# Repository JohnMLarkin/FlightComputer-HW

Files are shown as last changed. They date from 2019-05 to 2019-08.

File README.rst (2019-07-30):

***************************
HABOSC Flight Computer (HW)
***************************






Overview
========

The High Altitude Balloon Open Source Collection (HABOSC) is a set of interrelated tools for transmitting telemetry from a high altitude balloon, processing and storing that data, and providing user access to the stored data both during and after the flight. The system is designed to be flexible so it can adapt to the needs of various users.

One of the components of the HABOSC is the **Flight Computer**. The Flight Computer consists of a microcontroller and supporting hardware (battery, SD card, and XBee radio module) and comes in two configurations. The *standard* Flight Computer includes a clip to hold a half-size breadboard and the *mini* does not, reducing both its size and weight.

The Flight Computer is intended to be carried by individual experiment pods. The microcontroller can be flexibly programmed to interface with a wide variety of sensors. Data can be stored on the SD card or relayed to the ground using an XBee radio link to the Command Module. The microcontroller's software is written in C++ using the Arm\ :sup:`®` Mbed\ :sup:`™` OS.

This repository contains the *hardware* portion of the Flight Computer and supporting documentation.

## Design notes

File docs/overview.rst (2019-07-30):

High Altitude Balloon Open Source Collection
============================================

The High Altitude Balloon Open Source Collection (HABOSC) is a set of interrelated tools for transmitting telemetry from a high altitude balloon, processing and storing that data, and providing user access to the stored data both during and after the flight.  The system is designed to be flexible so it can adapt to the needs of various users.

The components of the collection are:

Command Module (hardware)
  This is the essential hardware system carried by the balloon.  The core tracking features are implemented using a GPS receiver and an Iridium satellite modem.
  The operations of the Command Module are coordinated by a microcontroller.  Bluetooth communication allows the Command Module to be configured for the flight shortly before launch (see the Launch Control tool below).
  Communication with experiment pods containing a Flight Computer (see below) is possible through a XBee 802.15.4 radio network operating at 2.4 GHz.

Command Module (microcontroller software)
  Written in C++ using the Arm\ :sup:`®` Mbed\ :sup:`™` OS, this is the code running on the microcontroller that ensures measurements are made and then transmitted to the Iridium satellite network.

Mission Control (server software)
  Running on a server, this Javascript code listens for telemetry packets relayed by the Iridium ground station via email.  The telemetry data is processed and stored in a MongoDB database.  Users interface with Mission Control through a web frontend.  Close to real-time mapping and graphical display of key telemetry is provided.

Launch Control (laptop or desktop application)
  Using the cross-platform Electron framework, this software allows a Bluetooth-enabled computer to communicate with the Command Module prior to launch.  It synchronizes the mission configuration between Command Module and Mission Control.  This application also allows users to monitor communication between the Command Module and linked Flight Computers during the prototyping and debugging phase on the ground.

Flight Computer (hardware)
  This printed circuit board holds an Arm Cortex-M3 microcontroller.  The microcontroller supports reading sensors and logging data to the attached SD card.  An XBee radio modem allows the microcontroller to synchronize its real-time clock with the Command Module as well as to relay data to the Command Module for transmission to Mission Control. An integrated rechargeable battery provides a reliable power source.  A version of the Flight Computer also provides a base for attaching a breadboard if custom circuitry is required.

Flight Computer (software library)
  This Mbed OS library allows users to easily integrate communication with the Command Module into their C++ code.

..  list-table:: Collection Links
    :header-rows: 1

    * - Component
      - Repository
      - Documentation
    * - Command Module (HW)
      - not yet available
      - not yet available
    * - Command Module (SW)
      - `GitHub <https://github.com/JohnMLarkin/Whitworth-CommandModule>`_
      - not yet available
    * - Mission Control
      - `GitHub <https://github.com/JohnMLarkin/Mission-Control>`_
      - not yet available
    * - Launch Control
      - `GitHub <https://github.com/JohnMLarkin/Whitworth-LaunchControl>`_
      - not yet available
    * - Flight Computer (HW)
      - `GitHub <https://github.com/JohnMLarkin/FlightComputer-HW>`_
      - not yet available
    * - Flight Computer (SW)
      - `GitHub <https://github.com/JohnMLarkin/FlightComputer-SW>`_
      - not yet available

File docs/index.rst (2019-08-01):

.. HABOSC Flight Computer (HW) documentation master file, created by
   sphinx-quickstart on Wed Jul 31 14:32:50 2019.
   You can adapt this file completely to your liking, but it should at least
   contain the root `toctree` directive.

.. include:: ../README.rst

.. toctree::
   :maxdepth: 3
   :numbered:
   :caption: Contents:

   overview
   fabrication
   parts
   assembly

Indices and tables
==================

* :ref:`genindex`
* :ref:`modindex`
* :ref:`search`

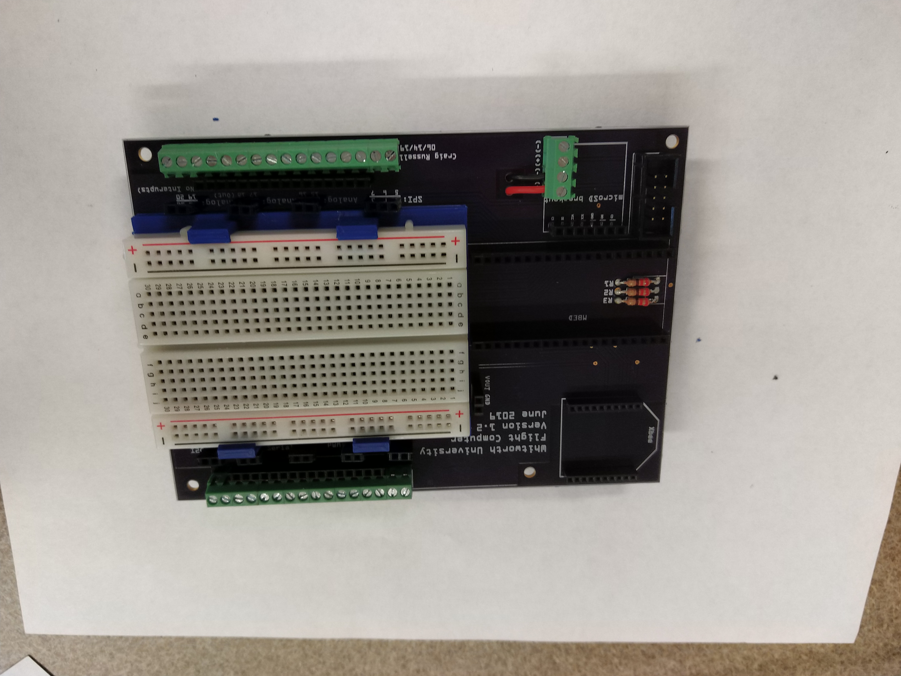
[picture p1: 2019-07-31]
docs/img/breadboard.jpg

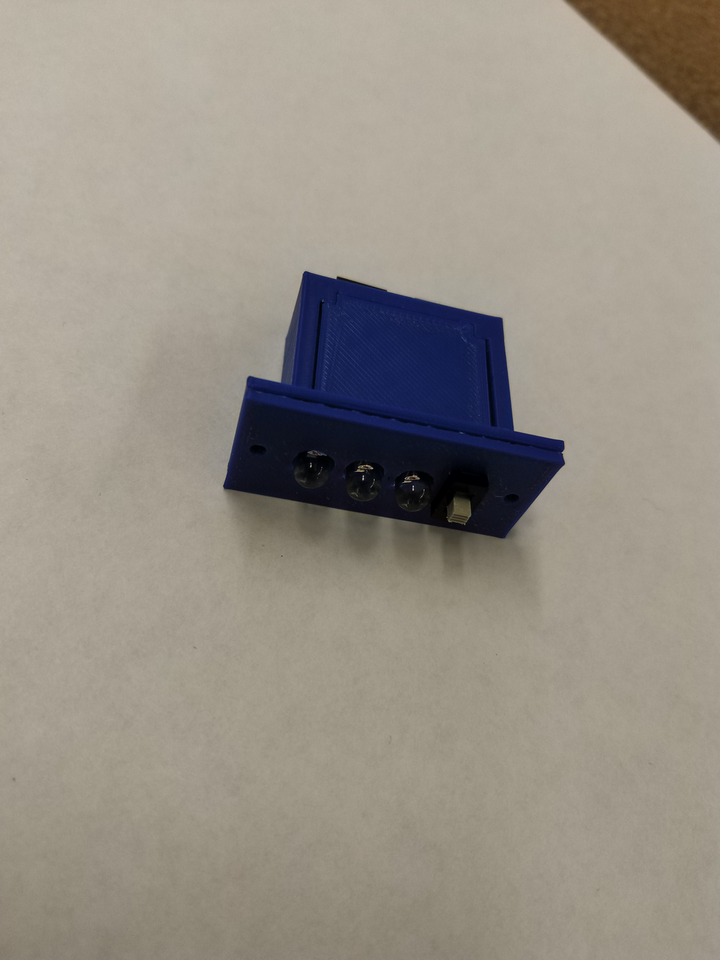
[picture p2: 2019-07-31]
docs/img/capOnBox.jpg

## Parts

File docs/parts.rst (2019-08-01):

Standard Parts
==============

Assembly of a Flight Computer requires the following electronic components and connection hardware.

..  list-table:: Common components for either Flight Computer
  :header-rows: 1
  :widths: auto

  * - Description
    - Manufacturer
    - Part Number
    - Quantity
    - Link
  * - 20 pin header socket (for mbed)
    - Sullins
    - PPPC201LFBN-RC
    - 2
    - `Digi-Key <https://www.digikey.com/product-detail/en/sullins-connector-solutions/PPPC201LFBN-RC/S7053-ND/810192>`__
  * - XBee socket (2 mm, 10 pin, set of 2)
    - Adafruit
    - 366
    - 1
    - `Digi-Key <https://www.digikey.com/product-detail/en/adafruit-industries-llc/366/1528-1392-ND/5629440>`__
  * - 2x5 IDC connector receptacle (female sockets)
    - Wurth Electronics
    - 61201023021
    - 2
    - `Digi-Key <https://www.digikey.com/product-detail/en/wurth-electronics-inc/61201023021/732-2102-ND/2060598>`__
  * - 2x5 IDC connector header (male pin)
    - Wurth Electronics
    - 61201021621
    - 2
    - `Digi-Key <https://www.digikey.com/product-detail/en/wurth-electronics-inc/61201021621/732-2094-ND/2060590>`__
  * - 2-pin screw terminal block, 3.5 mm pitch
    - Wurth Electronics
    - 691214110002
    - 18
    - `Digi-Key <https://www.digikey.com/product-detail/en/wurth-electronics-inc/691214110002/732-2747-ND/2508516>`__
  * - 220 |ohm|, 1/4 W resistor
    - 
    -
    - 3
    - `Digi-Key <https://www.digikey.com/product-detail/en/stackpole-electronics-inc/CF14JT220R/CF14JT220RCT-ND/1830334>`__
  * - LED, 5 mm, red
    - Cree
    - C503B-RCN-CW0Z0AA1
    - 1
    - `Digi-Key <https://www.digikey.com/product-detail/en/cree-inc/C503B-RCN-CW0Z0AA1/C503B-RCN-CW0Z0AA1-ND/1922930>`__
  * - LED, 5 mm, green
    - Cree
    - C503B-GCS-CY0C0791
    - 1
    - `Digi-Key <https://www.digikey.com/product-detail/en/cree-inc/C503B-GCS-CY0C0791/C503B-GCS-CY0C0791-ND/1922941>`__
  * - LED, 5 mm, blue
    - Cree
    - C503B-BCN-CV0Z0461
    - 1
    - `Digi-Key <https://www.digikey.com/product-detail/en/cree-inc/C503B-BCN-CV0Z0461/C503B-BCN-CV0Z0461-ND/1922945>`__
  * - Slide switch, SPDT
    - NKK Switches
    - AS13AP
    - 1
    - `Digi-Key <https://www.digikey.com/product-detail/en/nkk-switches/AS13AP/360-2124-ND/1014820>`__
  * - mbed LPC1768 microcontroller
    - NXP
    - OM11043
    - 1
    - `Digi-Key <https://www.digikey.com/product-detail/en/nxp-usa-inc/OM11043,598/568-4916-ND/2138502>`__
  * - XBee 3 radio module
    - Digi
    - XB3-24Z8PT
    - 1
    - `Digi-Key <https://www.digikey.com/product-detail/en/digi-international/XB3-24Z8PT/602-2191-ND/8130937>`__
  * - microSD breakout
    - SparkFun
    - BOB-00544
    - 1
    - `Digi-Key <https://www.digikey.com/product-detail/en/sparkfun-electronics/BOB-00544/1568-1345-ND/5824094>`__
  * - 7.4 V, 800 mAh LiPo battery with PCB
    - Tenergy
    - 31145
    - 1
    - `Tenergy <https://power.tenergy.com/search.php?search_query=31145>`__
  * - Male Tamiya connector, 20 AWG silicon wire
    - Tenergy
    - 80001-5
    - 1
    - `Tenergy <https://power.tenergy.com/standard-male-tamiya-connector-battery-side/>`__ 

A charger for the battery is also required. For the battery pack specified, an appropriate choice is the Tenergy TLP-2000 (`Tenergy <https://power.tenergy.com/tenergy-tlp-2000-smart-charger-for-li-ion-lipo-battery-packs-3-7v-14-8v/>`__). This charger can be shared among multiple Flight Computers.

Connecting the Flight Computer PCB to the external interface also requires flat ribbon cable (10 conductors).  We buy this by the meter (`Digi-Key <https://www.digikey.com/product-detail/en/wurth-electronics-inc/63911015521CAB/732-11801-ND/8324551>`__) and cut an appropriate length.

We also use standard perf board (like `this <https://www.digikey.com/product-detail/en/vector-electronics/64P44XXXP/V1043-ND/37918>`__) in the assembly of the external interface. You just need a 2 hole by 5 hole piece so this might easily be scrap from some other project.

Additions for Standard Flight Computer
--------------------------------------

If you are assembling a **standard** Flight Computer, you will also need female header sockets in various lengths (with 2.54 mm pitch).  Those lengths and the number required are:

* 16 pins (2)
* 7 pins (1)
* 3 pins (1)
* 2 pins (9)

We use breakaway female header strip and cut it to length. Cutting always sacrifices one pin and then the edges are smoothed. We have had good success with Adafruit's 598 (5 pack of 36-pin strips) and the price is less than many other options (`Digi-Key <https://www.digikey.com/products/en?keywords=1528-2537-ND>`__).

The breadboard clip on the standard Flight Computer (one of the custom 3D printed components) is designed for a half-size solderless breadboard (for example, Adafruit's `64 <https://www.digikey.com/product-detail/en/adafruit-industries-llc/64/1528-2182-ND/7241427>`__). If you want something more permanent than a solderless breadboard, Adafruit makes a `perma-proto half-sized breadboard PCB <https://www.digikey.com/products/en/prototyping-fabrication-products/prototype-boards-perforated/636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>`__ that has the same mounting hole spacing as our breadboard clip.

Addition for Mini Flight Computer
---------------------------------

If you are assembling a **mini** Flight Computer, you will also need a 3-pin screw terminal block (with 3.5 mm pitch). We use Wurth Electronics part 691214110003 (`Digi-Key <https://www.digikey.com/product-detail/en/wurth-electronics-inc/691214110003/732-2748-ND/2508517>`__).

.. |ohm| unicode:: U+03a9 ..  capital omega

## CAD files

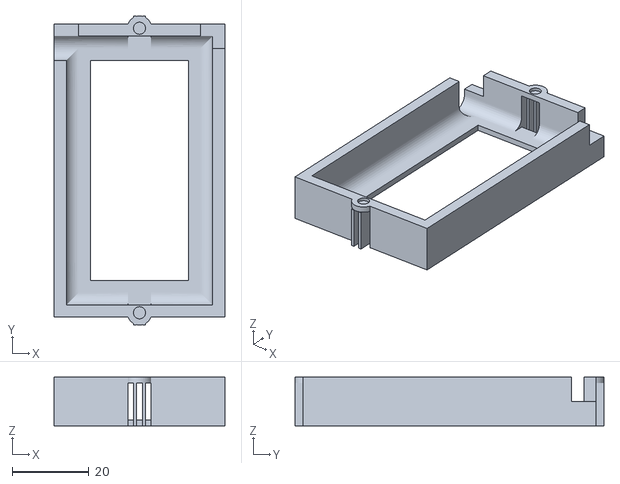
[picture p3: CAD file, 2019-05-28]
3d_print/battery_holder/battery clip.stl
44.5 x 80.4 x 12.7

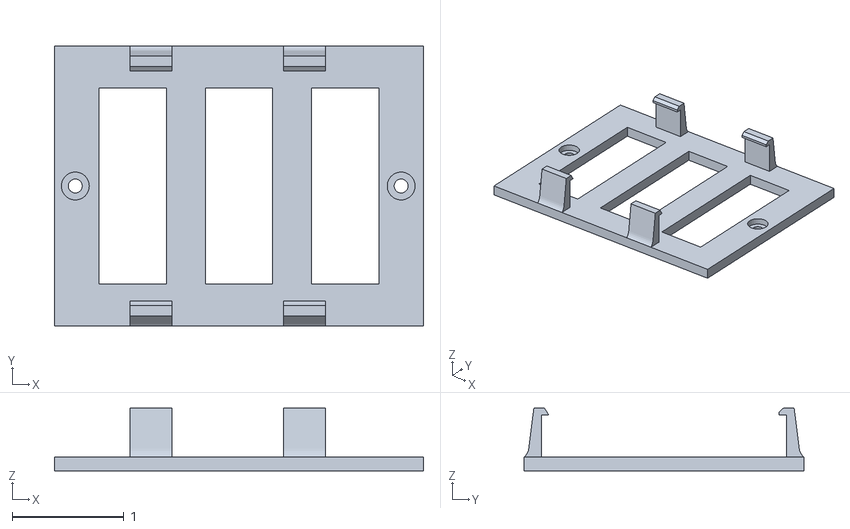
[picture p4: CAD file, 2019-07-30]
3d_print/breadboard_clip/breadboard clip V2.stl
3.30 x 2.50 x 0.563

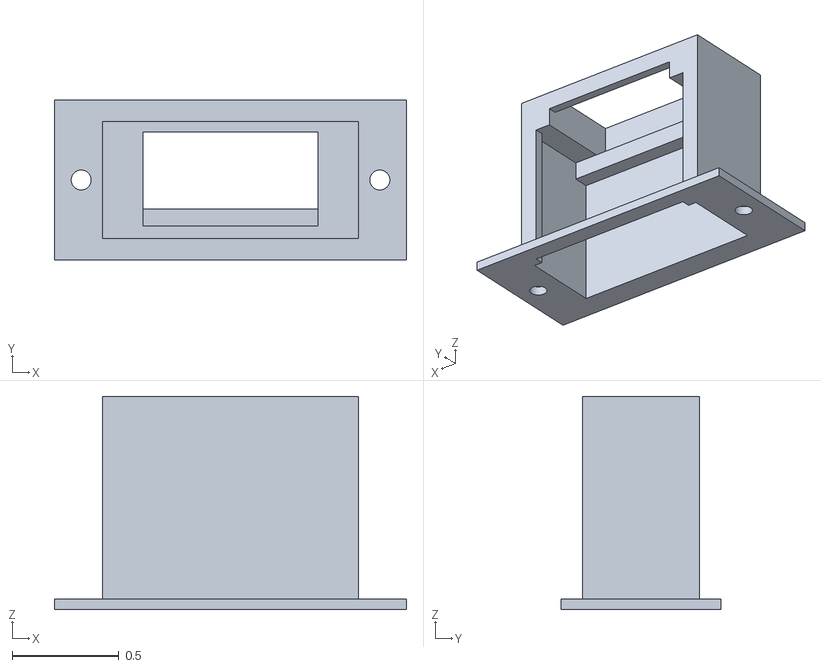
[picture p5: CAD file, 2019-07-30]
3d_print/external_interface/body-ext-interface.stl
1.65 x 0.75 x 1.00

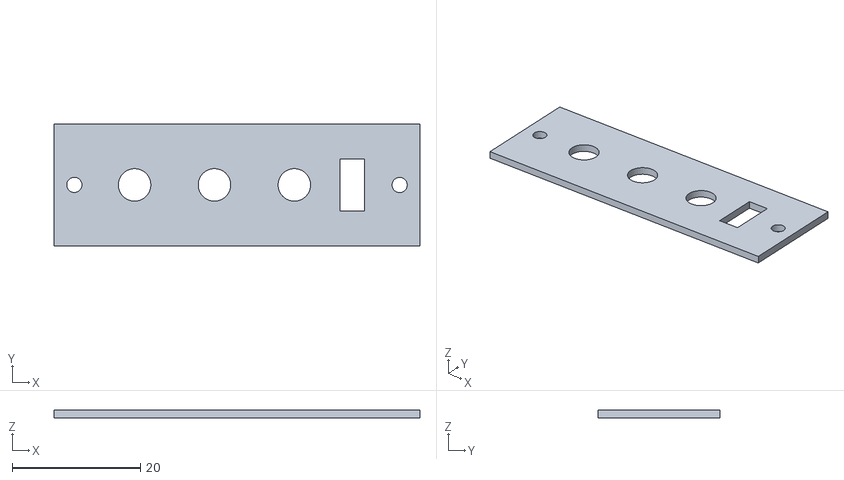
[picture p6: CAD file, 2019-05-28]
Components-3D_Printed/STL Files/3 led switch mount cap.stl
57.1 x 19.0 x 1.27

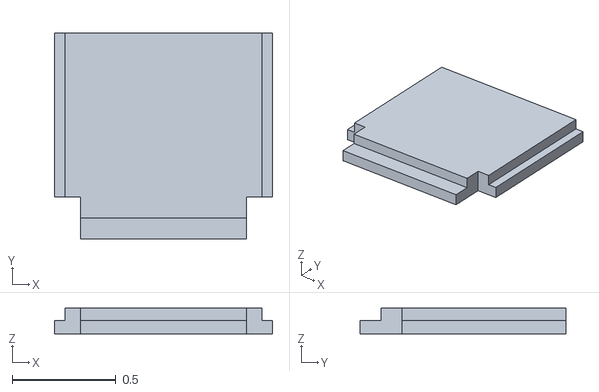
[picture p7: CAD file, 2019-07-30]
3d_print/external_interface/panel-ext-interface.stl
1.05 x 0.99 x 0.125

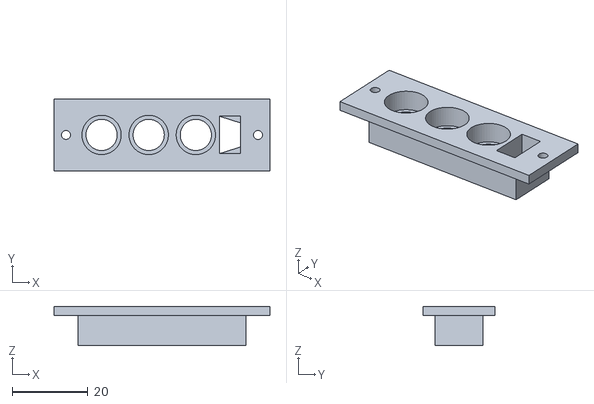
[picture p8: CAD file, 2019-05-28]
Components-3D_Printed/STL Files/3 led switch mount.stl
57.1 x 19.0 x 10.4

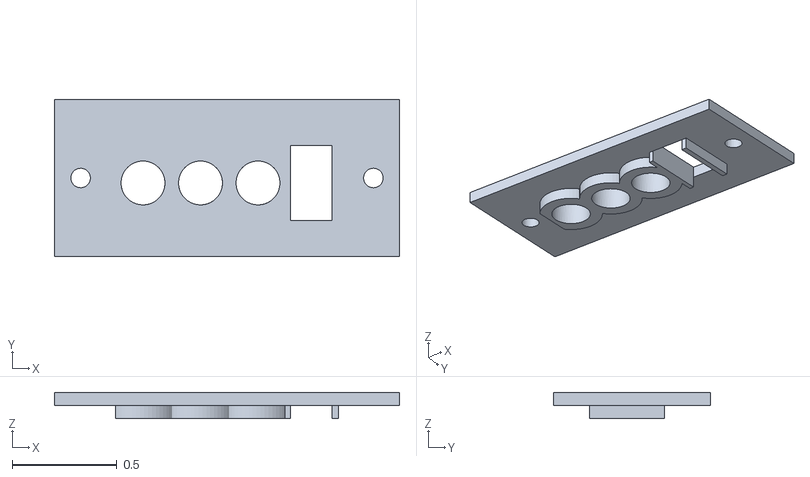
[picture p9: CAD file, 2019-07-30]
3d_print/external_interface/face-ext-interface.stl
1.65 x 0.75 x 0.125

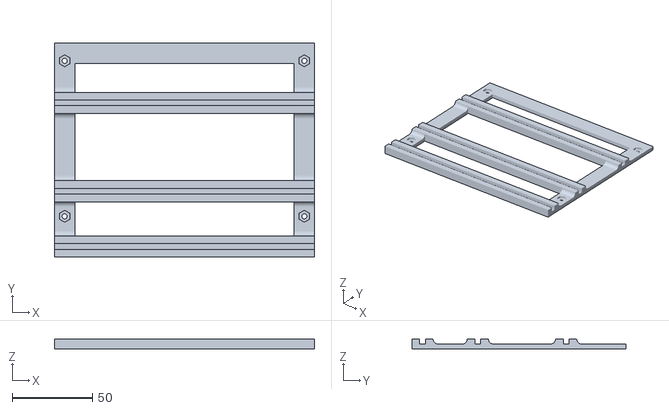
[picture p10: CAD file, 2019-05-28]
Components-3D_Printed/STL Files/ctrl pod wall.stl
161.9 x 133.4 x 6.48

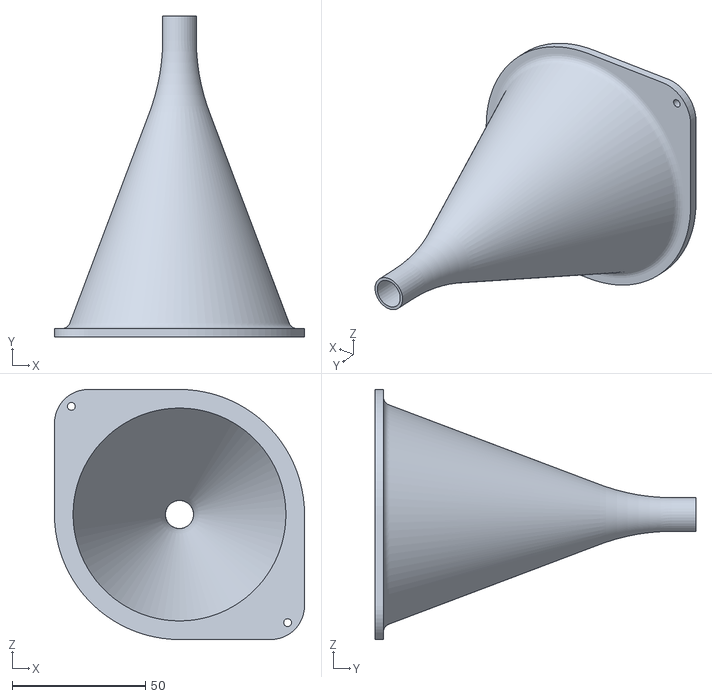
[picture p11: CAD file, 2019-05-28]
Components-3D_Printed/STL Files/fan couple.stl
94.0 x 120.6 x 94.0

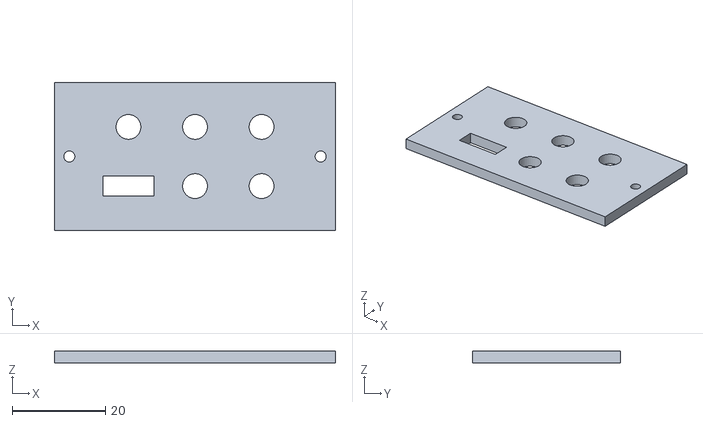
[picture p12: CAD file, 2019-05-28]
Components-3D_Printed/STL Files/5 led cap.stl
60.3 x 31.8 x 2.62

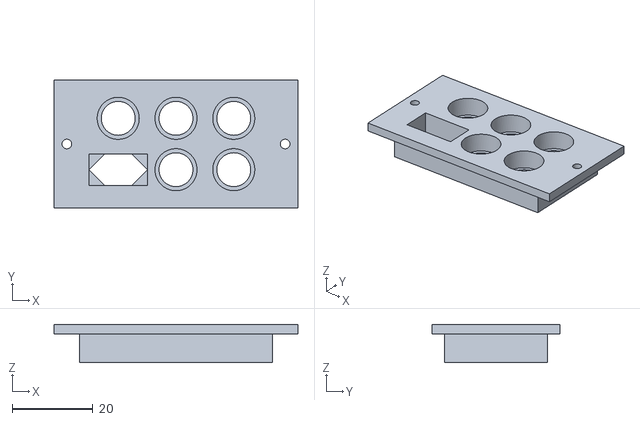
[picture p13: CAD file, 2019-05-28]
Components-3D_Printed/STL Files/5 led mount.stl
60.3 x 31.8 x 9.40

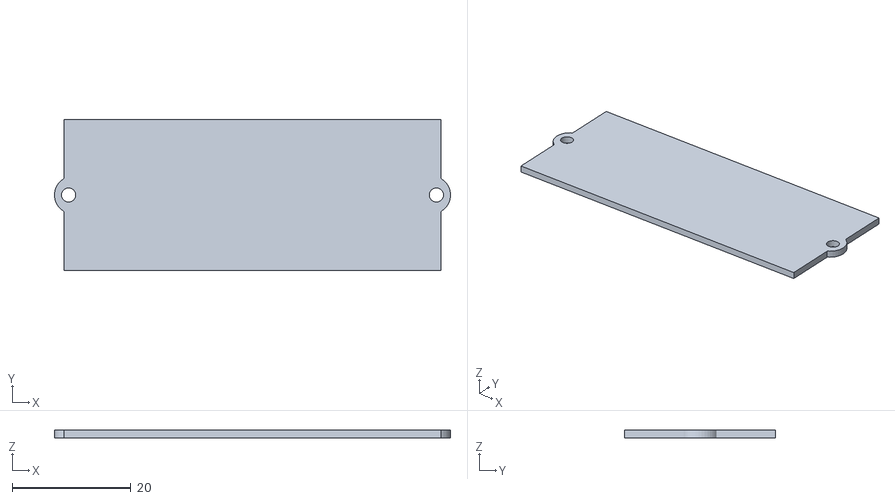
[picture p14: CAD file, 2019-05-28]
Components-3D_Printed/STL Files/power channel cap.stl
66.7 x 25.4 x 1.27

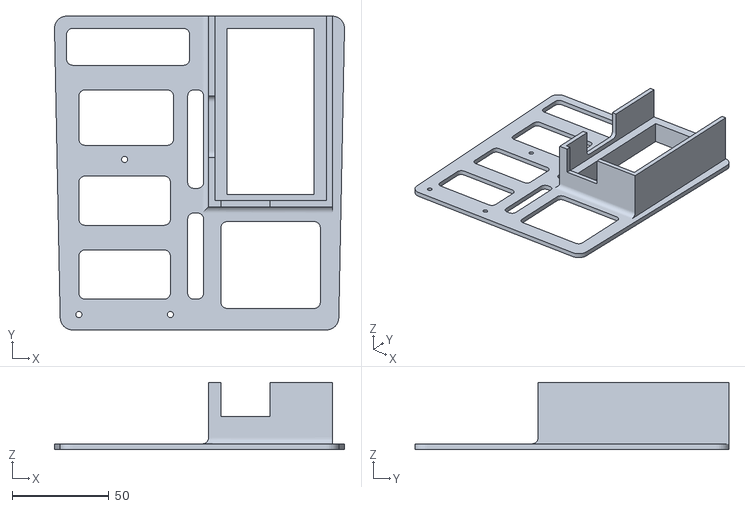
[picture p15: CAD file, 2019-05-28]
Components-3D_Printed/STL Files/top layer ctrl pod.stl
149.6 x 161.9 x 34.8

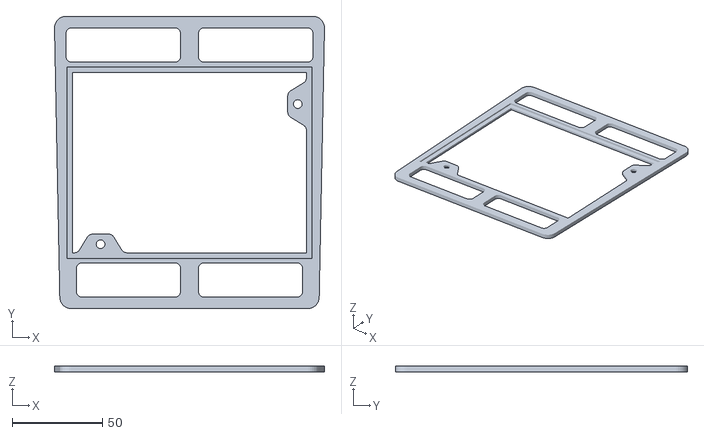
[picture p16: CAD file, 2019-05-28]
Components-3D_Printed/STL Files/middle layer ctrl pod.stl
149.6 x 161.9 x 3.05

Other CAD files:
Components-3D_Printed/STL Files/breadboard clip.stl
Components-3D_Printed/STL Files/power channel.stl
Components-3D_Printed/STL Files/bottom layer cap.stl
Components-3D_Printed/STL Files/bottom layer ctrl pod.stl
3d_print/archive/other/ipt/5 led cap.ipt
3d_print/archive/other/ipt/5 led mount.ipt
3d_print/archive/other/ipt/bottom layer cap.ipt
3d_print/archive/other/ipt/bottom layer ctrl pod.ipt
3d_print/archive/other/ipt/ctrl pod wall.ipt
3d_print/archive/other/ipt/fan couple.ipt
3d_print/archive/other/ipt/middle layer ctrl pod.ipt
3d_print/archive/other/ipt/power channel cap.ipt
3d_print/archive/other/ipt/power channel.ipt
3d_print/archive/other/ipt/top layer ctrl pod.ipt
3d_print/archive/other/stl/bottom layer cap.stl
3d_print/archive/other/stl/bottom layer ctrl pod.stl
3d_print/archive/other/stl/power channel.stl
3d_print/archive/v1_0/breadboard_clip/breadboard clip.ipt
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

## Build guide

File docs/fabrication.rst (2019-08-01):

Custom Parts
============

The Flight Computer requires the fabrication of some custom components: a printed circuit board (PCB) and several 3D printed parts.

Printed Circuit Boards
----------------------

The PCB files can be found on `GitHub <https://github.com/JohnMLarkin/FlightComputer-HW>`_ in the ``pcb/standard`` folder for the standard-sized Flight Computer and ``pcb/mini`` folder for the mini. The most recent versions are at the top-level of these folders but older versions can be found in the ``archive`` folder.

The PCBs were designed using `Fritzing <https://fritzing.org>`_, an easy to use (and free) electronic prototyping tool suitable for simple designs. Fritzing design files have the extension ``fzz``.  This design is then exported from Fritzing as a collection of *gerber* files, saved as a single zip archive.

There are several companies that can make the PCBs for you from the gerber files. We have had great success with `OSH Park <https://oshpark.com>`_. If you want to order the most recent version of either board directly from them, you can do so (`standard <https://oshpark.com/shared_projects/nXXAHcDw>`_, `mini <https://oshpark.com/shared_projects/EYISRbfR>`_). In July 2019 these were available for $109 (standard, set of 3) or $40 (mini, set of 3) before shipping and any applicable tax.

3D Printed Parts
----------------

A fully assembled Flight Computer also requires some 3D printed parts: a battery holder, a breadboard clip (only for the standard Flight Computer), and an external interface to be mounted on the outside of the pod that holds a switch and indicator LEDs. These can be found in the same GitHub repository as the PCB files (`GitHub <https://github.com/JohnMLarkin/FlightComputer-HW>`_) but under the ``3d_print`` folder. The parts were designed in AutoDesk Inventor (``ipt`` files) and exported for 3D printing as ``stl`` files.

We have printed these parts using an Ultimaker 2+ with ABS filament. The best results have been obtained with a 0.10 mm layer height, 30% fill, and 0.9 mm shell thickness. These settings are most important for the breadboard clips, as these may break off if the infill is too weak.

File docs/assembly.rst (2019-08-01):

Assembling the Flight Computer
==============================

You are ready to begin assembly after you have had the PCB fabricated and printed the custom components.  Both sizes of the Flight Computer require the battery holder and the external interface (body, face, and panel parts).  If you are assembling a **standard** Flight Computer, you will also need the breadboard clip.

The assembly of both the **standard** and **mini** Flight Computers is nearly identical. This guide describes the process for the **standard** version.

Main PCB Assembly
-----------------

1. Solder all the resistors, headers, screw terminals, and the male IDC header to the board. Starting with the shortest pieces (the resistors) and progressively attaching taller parts seems to work well. When you are done, it should look like the board shown in Fig. |nbsp| 1.

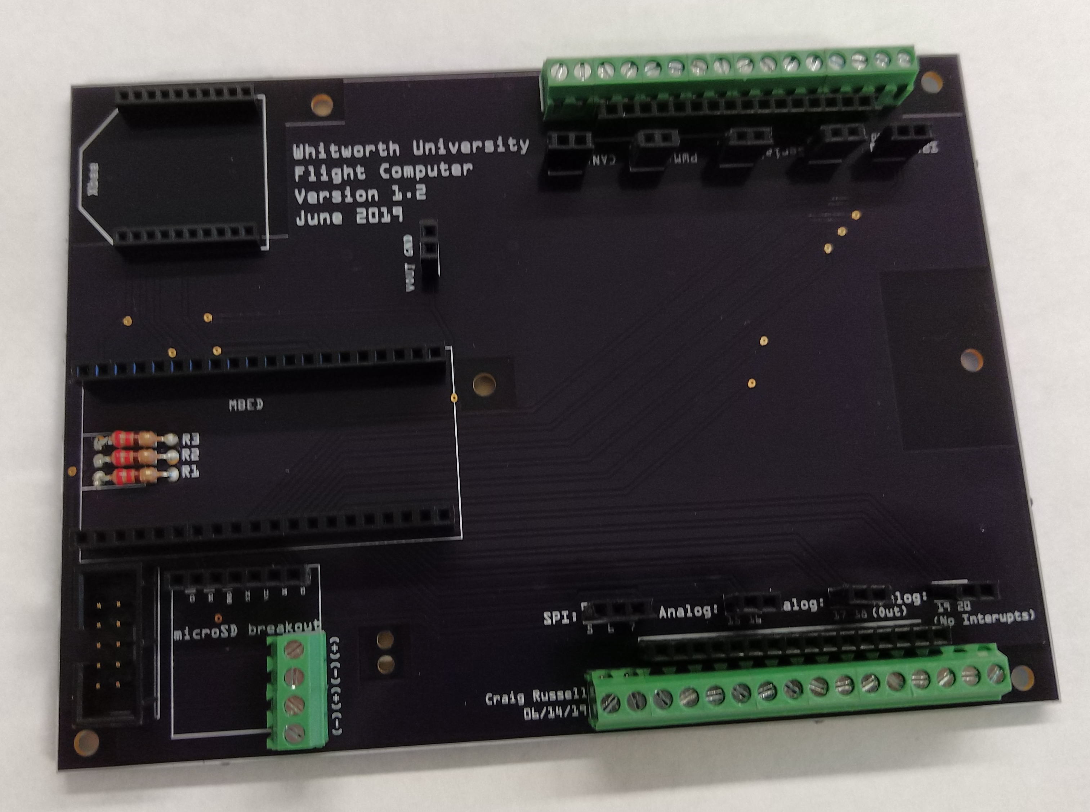
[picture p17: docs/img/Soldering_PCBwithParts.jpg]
  

    Fig. 1. PCB after all of the electronic components have been soldered.

2. Place the LiPo battery into the battery holder, with the wires coming out the notch on the side of the holder. Next, run the power and ground connections through the pair of holes in the PCB, as shown in Fig. |nbsp| 2. Secure the wires in the screw terminals next to the SD card reader headers (the two closest to the header). The black wire goes to terminal with a minus sign, and the red wire goes to the terminal with a plus sign.

  

    Fig. 2. LiPo battery in holder. The LiPo wires pass through a pair of holes in the PCB located near a screw terminal block on the opposite side.

3. Using 5/16-inch #4-40 screws and appropriate nuts, secure the battery holder to the bottom of the PCB. The nuts should fit tightly into the battery holder and not rotate while the screws are tightened. Similarly, if assembling a standard Flight Computer, attach the breadboard clip to the top of the PCB, as shown in Fig. |nbsp| 3.

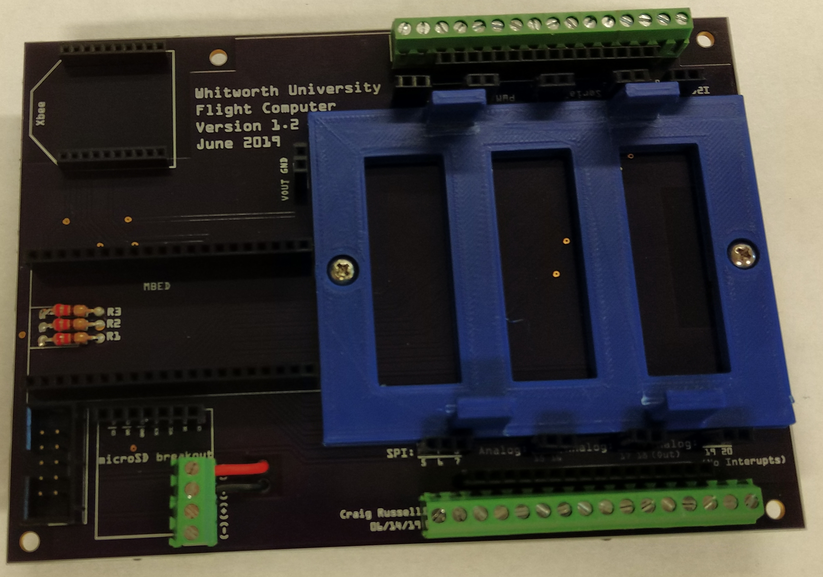
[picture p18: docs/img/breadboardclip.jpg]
  
  
    Fig. 3. PCB with breadboard clip secured and battery wires connected to screw terminals.

4. Carefully snap a breadboard into the breadboard clip. It is best to place one side under the clips, then force the other side down until it snaps in.

5. The charging adapter needs to be attached to the remaining screw terminals near the SD card reader header. The black wire is attached to the minus terminal nearest the edge of the board and the red wire is to the positive terminal next to it, as shown in Fig. |nbsp| 4.

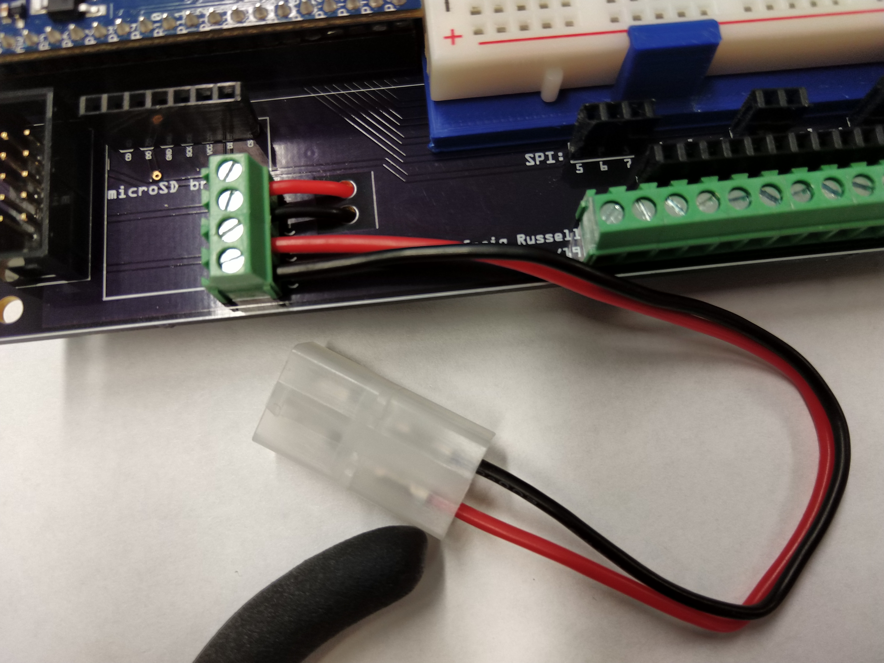
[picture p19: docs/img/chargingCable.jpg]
  

    Fig. 4. Charging adapter connected to the two screw terminals closest to the edge of the PCB. The wires from the battery are connected to the other terminals.

External Interface Assembly
---------------------------

1. The external interface consists of three 3D printed parts: the body, the face, and the panel. You will also need a 2 hole by 5 hole rectangle of perforated board to hold components in place inside of the interface.

2. Solder short lengths (2-3 inches) of wire to each lead of the DPST switch. Use shrink tube to cover the solder joints and reduce the amount of bare metal visible.

3. Place the switch into the slot in the interface face, along with the three LEDs (see Fig. |nbsp| 5). When placing the LEDs, it works best to align them so that the two leads are perpendicular to the long edges of the face, with the three ground leads (the shorter legs) on the same side.

  

    Fig. 5. Face component of the external interface with switch and LEDs inserted.

4. You are now going to connect the three ground leads of the LEDs together so there is only one ground connection to the external interface.  The two LEDs nearest to the switch need to have their ground legs bent so they can be soldered to the outermost LED’s ground leg. Remember to put heat shrink on before bending these legs. Now you should have three LED positive connections, one shared LED ground connection, and three switch connections as shown in `Fig. 6`_.

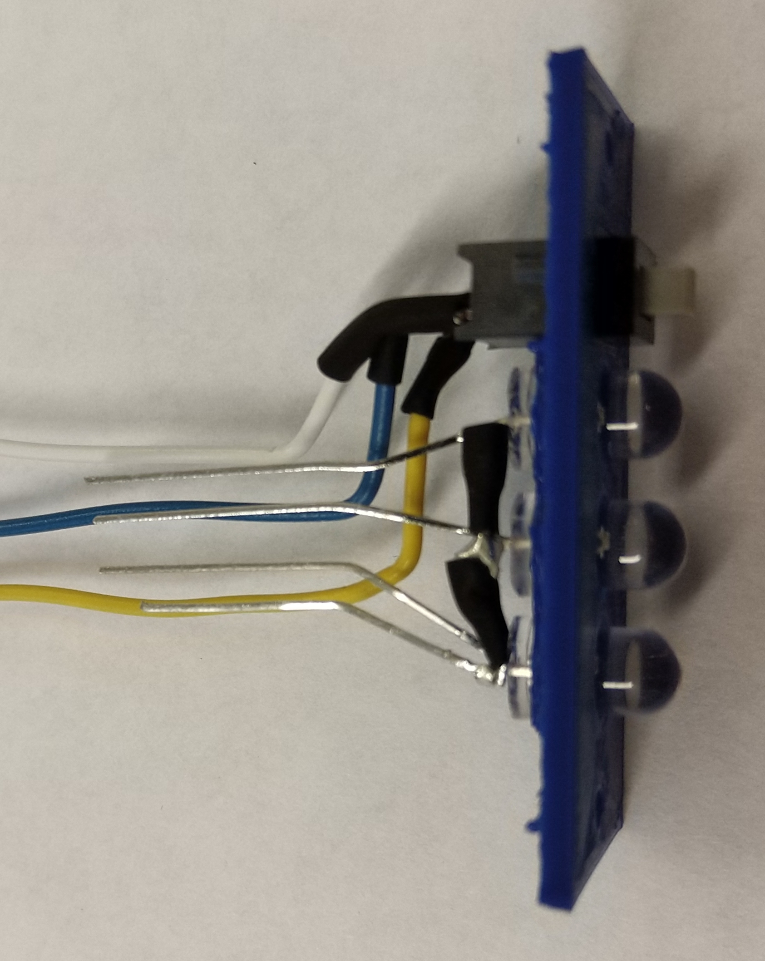
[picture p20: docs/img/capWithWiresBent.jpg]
  

    Fig. 6. The bare metal lead at the bottom of this image is the ground connection to the three LEDs (with the connections between adjacent LEDs covered in shrink tube).

5. We now need to bend these 7 connections to approximately where they will be when they connect to the male IDC header. We will use the 2-by-5 perforated board piece to help align them. The following table shows where each wire will pass through the perforated board and then connect to the IDC header. The 2-by-5 header has three empty connections (labeled NC).

  .. table:: IDC header connections (under side view). If properly oriented the polarity notch is at the top and the ground indicator (triangle on header) is at the top left.
    :widths: grid
    :name: connectionTable

    ========= ========= ========= ========= =========
    LED GND   LED 1+    LED 2+    LED 3+    NC
    SW up     NC        NC        SW center SW down
    ========= ========= ========= ========= =========

6. Position the wires to match up with the bottom of the connector and use the perforated board piece for proper spacing. Once they are positioned, place the interface face inside the interface body, letting the wires go out the back (`Fig. 7`_). Mark where the wires cross over the beam at the back of the body piece. You will need to cut the wires so that they do not extend beyond this beam (`Fig. 8`_).

  

    Fig. 7. Temporary assembly of face into body in order to determine where to cut wires. A beam across the back of the body will help hold the IDC header. The wires should be cut at side of the beam opposite the face, as indicated by the dashed line in the photograph.
  
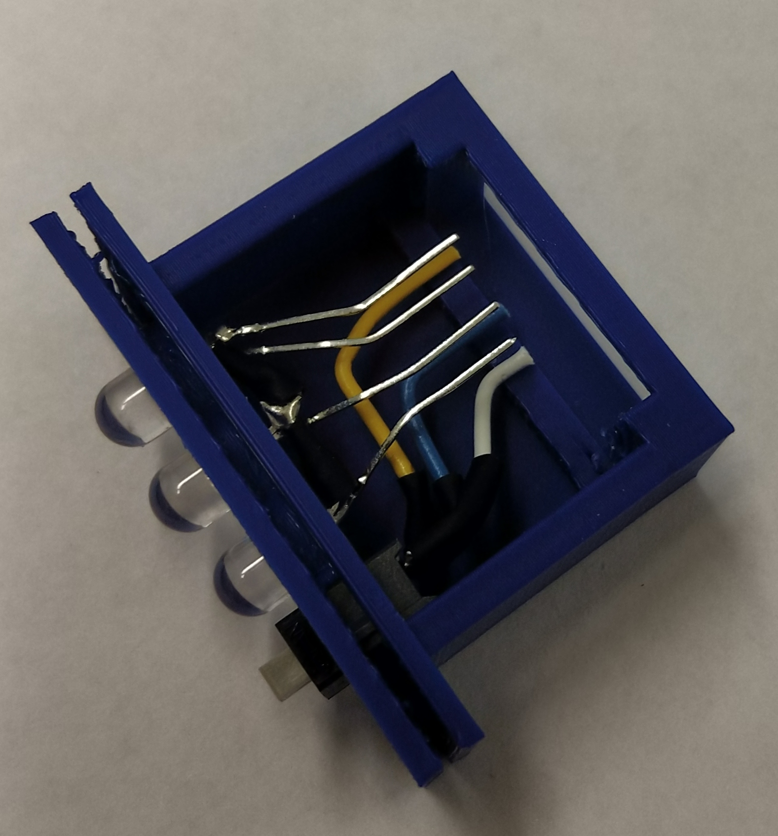
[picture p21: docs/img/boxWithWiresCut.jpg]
  

    Fig. 8. Temporary assembly of face into body. Wires have now been cut to the correct length.

7. Once the wires are cut and stripped, remove the face and body and then replace the perforated board piece. This piece will sit on the inner side of the beam to help secure the IDC connector. Solder on the connector, making sure the wires connect as specified in the `table <connectionTable_>`_ and shown in `Fig. 9`_.

  

    Fig. 9. Interior components of interface soldered to IDC header.

8. Place the internal components inside the interface body. Push down so the IDC header is secure beyond the beam, as shown in `Fig. 10`_. Then slide the side panel inside as well. If the panel won't fit, the small plastic extrusion on the switch may need to be filed off. Replace the face over the switch and LEDs. It may be useful to use needle-nose pliers to pull them all the way through. The result should look like `Fig. 11`_.

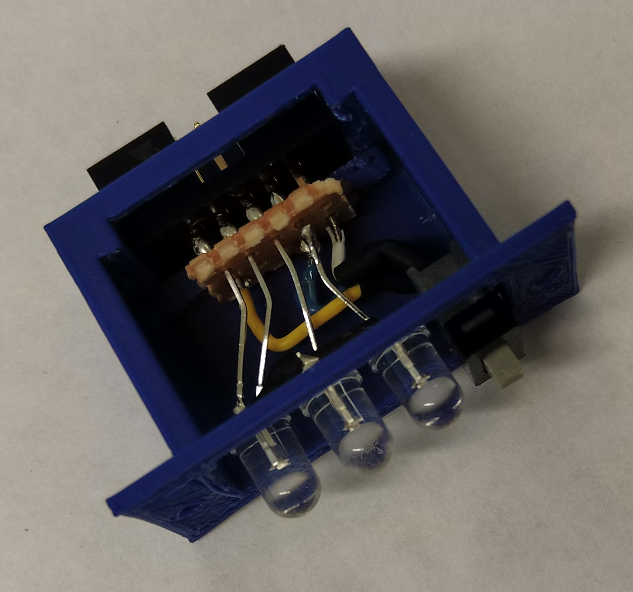
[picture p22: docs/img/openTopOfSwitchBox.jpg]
  

    Fig. 10. Interior components placed inside of interface body.

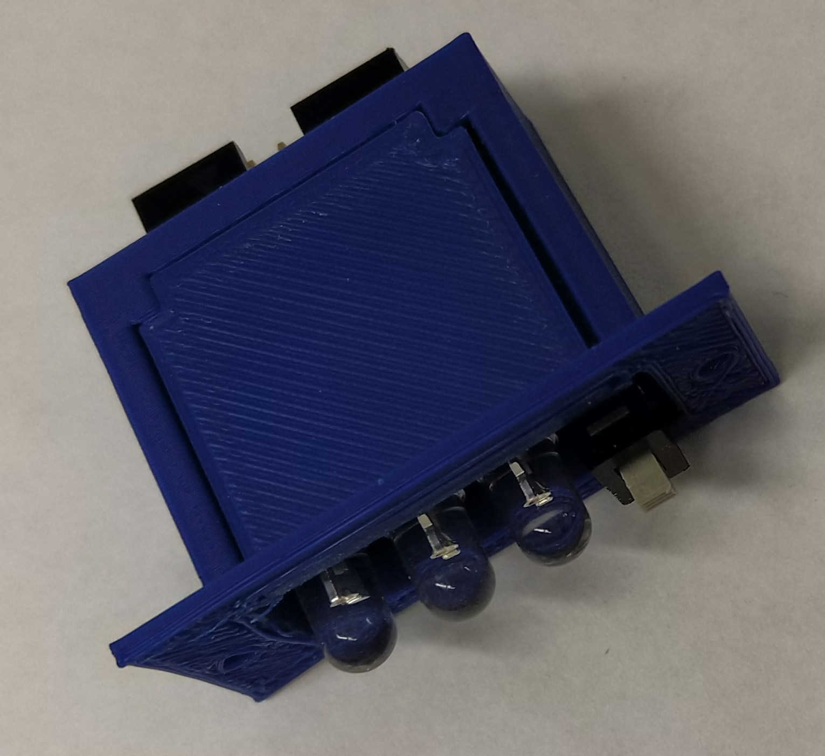
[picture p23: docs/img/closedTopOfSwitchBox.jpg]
  

    Fig. 11. Interface panel is slid into the interface body.

9. Now use two 5/32-inch #2-56 screws to secure the face to the body, sealing the external interface as one piece.  `Fig. 12`_ shows the completely assembled external interface.

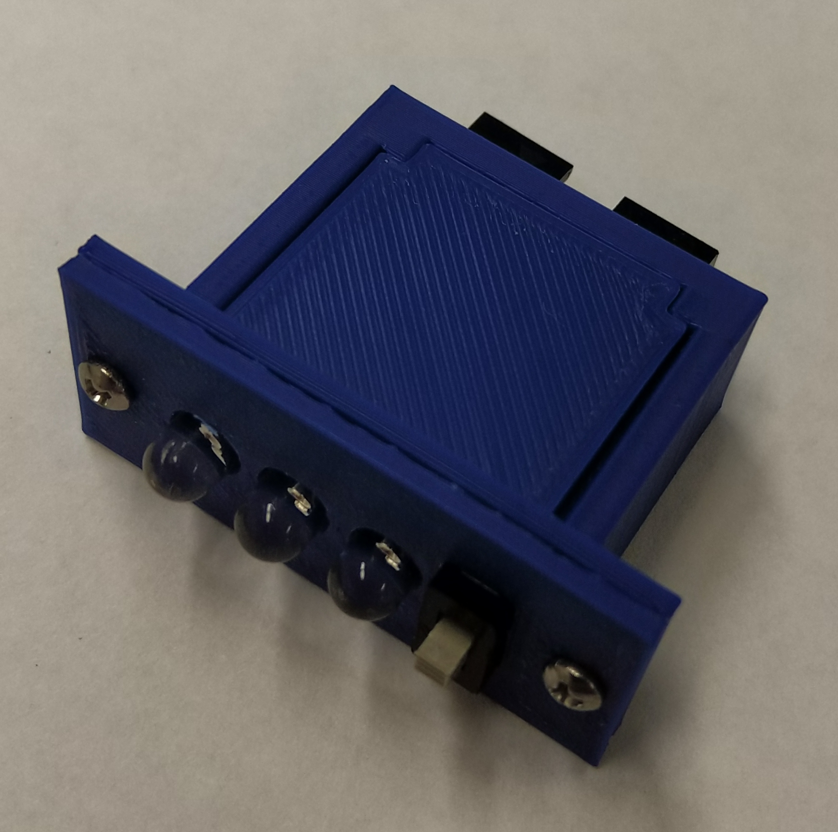
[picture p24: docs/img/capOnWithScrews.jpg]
  

    Fig. 12. Completed external interface.
    
Final Assembly
--------------

1. The female IDC connectors need to be put on the ends of an approximately 6 inch long section of ribbon cable. The IDC receptacles must be oriented so the ground indicators (the triangle on the side) are on the same side as the red wire on the ribbon cable (see `Fig. 13`_).

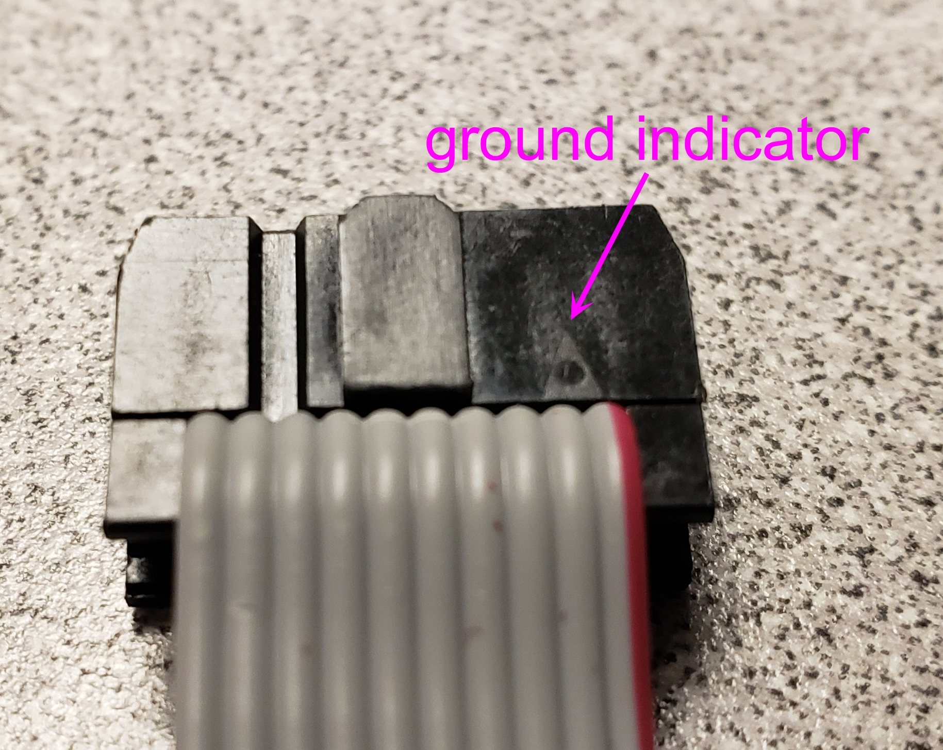
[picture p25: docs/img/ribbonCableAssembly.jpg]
  

    Fig. 13. The ground indicator on the IDC receptacle needs to be on the same edge as the red wire on the ribbon cable.

2. Place the LPC1768 microcontroller, XBee module, and SD breakout board into the corresponding headers on the PCB.

3. Connect the external interface to the PCB using the ribbon cable. The Flight Computer is now fully assembled and ready for use (see `Fig. 14`_).

  
    
    Fig. 14. Fully assembled standard Flight Computer.

.. |nbsp| unicode:: 0xA0
   :trim:

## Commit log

2019-05-28 Fritzing PCB design files
    Upload of work done by Kevin Teo during summer 2017
    [launch computer v1.fzz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]
2019-05-28 AutoDesk Inventor files for 3D printed components
    Created by Kevin Teo during summer 2017
    [3 led switch mount cap.ipt, 3 led switch mount cap.stl, 3 led switch mount.ipt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]
2019-06-04 created a new version of the flight computer, and a smaller version
    [flightComputerV1_1.fzz, miniFlightComputerV1.fzz]
2019-07-30 Update repo structure
    [FlightComputerV1_0.fzz, FlightComputerV1_1.fzz, FlightComputerV1_2.fzz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]
2019-07-30 Reorganize 3D printer files
    [3 led switch mount cap.ipt, 3 led switch mount cap.stl, 3 led switch mount.ipt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]
2019-08-01 Fix error in pcb/standard folder ref
